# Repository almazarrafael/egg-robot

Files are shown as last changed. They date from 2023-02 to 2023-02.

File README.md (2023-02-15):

# egg-robot
Self-balancing PID controlled robot on the Arduino.

egg is a robot that is capable of self-balancing. This is done through a PID controller that takes in IMU data that determines its pitch angles and outputs motor values. The idea is to correct the error between the actual pitch angle to a setpoint. The setpoint angle is the angle where the robot is standing vertically. The PID controller then takes this error and outputs values that the motors can use. Three different components are at play when it comes with PID controllers. Proportional, integral and derivative components which include their own gains (Kp, Ki, Kd). These gains need to be tuned accordingly in order to achieve self-balancing.

| egg Front View | dumpling Side View |
|:---:|:---:|
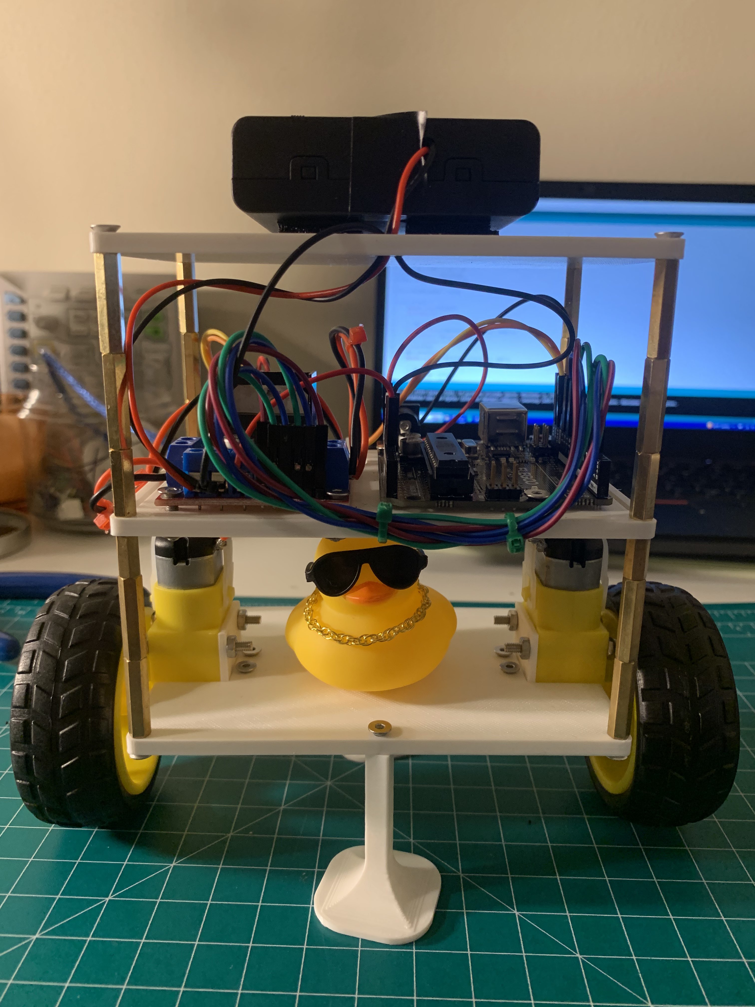
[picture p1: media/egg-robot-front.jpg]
dumpling
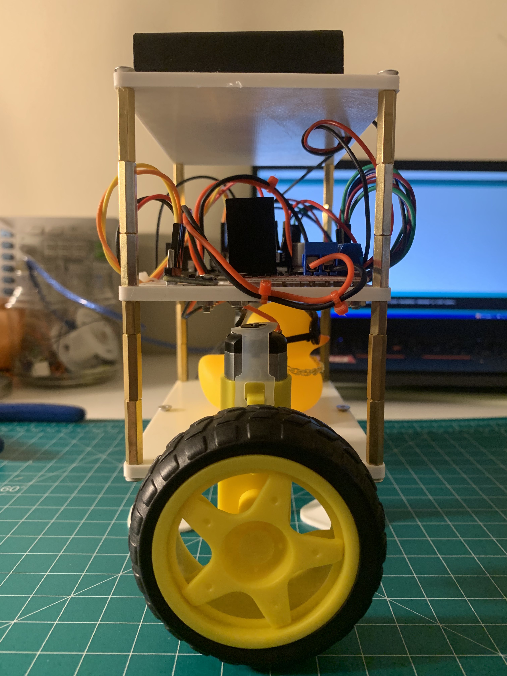
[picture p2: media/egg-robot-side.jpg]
dumpling_top
|||

### Parts List

- Arduino
- 2x TT motors
- L298N motor driver
- MPU6050 IMU
- 6V Battery pack
- 3D printed chassis
  - Base plate
  - Top plate for components
  - Top plate for battery
  - Motor mounts for base plate
  - Display stands
- Standoffs
- Various harnessing

### Tuning strategy

- Set Ki and Kd to 0.
- Increase Kp gain
  - Too low then the robot can't recover
  - Too high then the robot starts oscillating
  - A good Kp will allow the robot to stand almost on its own
- Once Kp is chosen, increase Kd. An increase in Kd will mitigate oscillations but if set too high then it will cause jitters.
- A PD controller will have steady-state error and this can be seen when the robot tilts one way consistently.
- Increase Ki until steady state error is gone.

### Resources

- [PID](http://brettbeauregard.com/blog/2011/04/improving-the-beginners-pid-introduction/)
- [PID tuning guide](https://www.youtube.com/watch?v=uyHdyF0_BFo)
- [MPU6050](https://lastminuteengineers.com/mpu6050-accel-gyro-arduino-tutorial/)
- [L298N](https://lastminuteengineers.com/l298n-dc-stepper-driver-arduino-tutorial/)

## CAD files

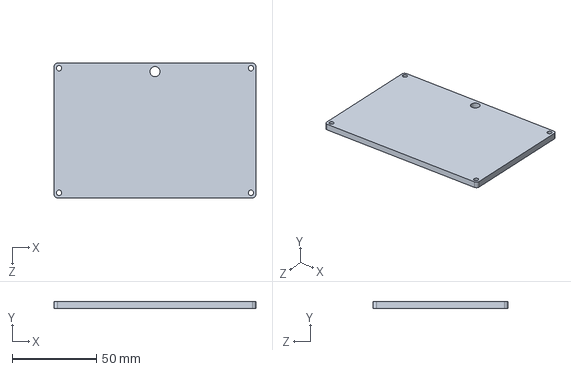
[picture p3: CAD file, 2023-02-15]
egg-models/SOLIDWORKS/top-plate-battery.SLDPRT
120.0 x 4.00 x 80.0 mm

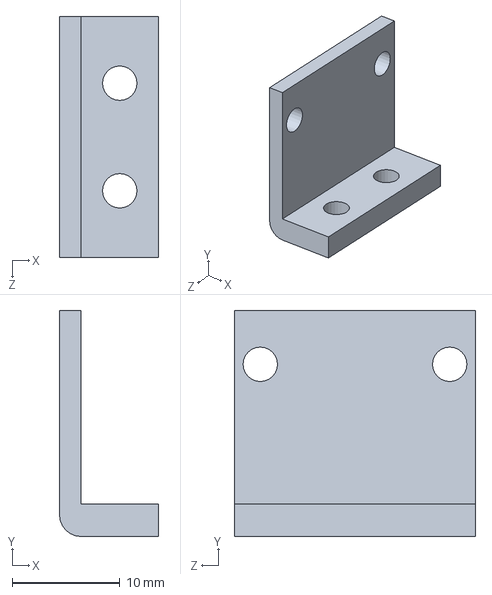
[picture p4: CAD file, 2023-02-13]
egg-models/SOLIDWORKS/motor-mount.SLDPRT
9.20 x 21.0 x 22.4 mm

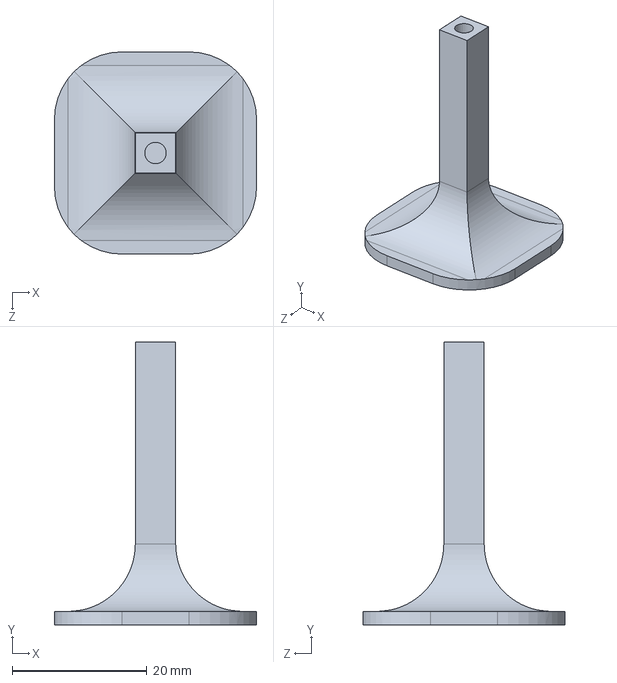
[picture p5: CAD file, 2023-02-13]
egg-models/SOLIDWORKS/display-stand.SLDPRT
30.0 x 42.0 x 30.0 mm

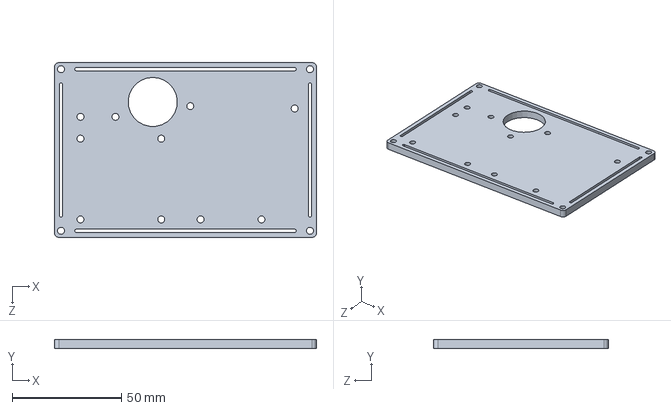
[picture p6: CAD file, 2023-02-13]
egg-models/SOLIDWORKS/top-plate.SLDPRT
120.0 x 4.00 x 80.0 mm

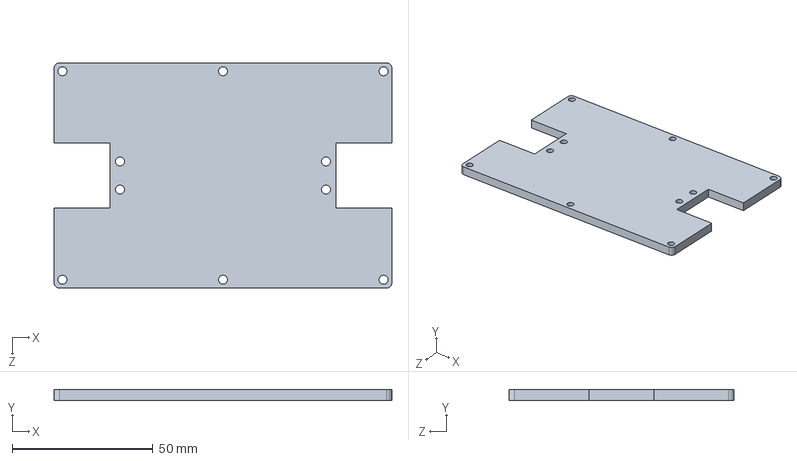
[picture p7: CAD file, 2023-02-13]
egg-models/SOLIDWORKS/base-plate.SLDPRT
120.0 x 4.00 x 80.0 mm

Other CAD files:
egg-models/STL/base-plate.STL
egg-models/STL/display-stand.STL
egg-models/STL/motor-mount.STL
egg-models/STL/top-plate-battery.STL
egg-models/STL/top-plate.STL

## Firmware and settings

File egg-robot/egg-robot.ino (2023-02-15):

#include "Wire.h"
#include <MPU6050_light.h>

// MPU
MPU6050 mpu(Wire);

// Pin definitions
#define enA 11 // PWM 
#define in1 12 // Forward
#define in2 13 // Backward

#define enB 3 // PWM
#define in3 4 // Backward
#define in4 5 // Forward

// PID values
float yRotation; // PID input
int output;
float setpoint = 0;
int sampleTime = 10;
int outMin = -255;
int outMax = 255;

// PID calculation
unsigned long lastTime;
float errSum;
float lastErr;

// PID tuning
double kp = 100; // Ku = 35
double ki = 0.5 * sampleTime;
double kd = 0.05 / sampleTime;

bool fallDetected = false;

void setup() {
    Serial.begin(115200);
    Wire.begin();

    // MPU
    Serial.println("MPU6050 calibration: START");
    byte status = mpu.begin();
    while (status != 0) { }
    delay(1000);
    mpu.calcOffsets();
    Serial.println("MPU6050 calibration: END");
    
    // Motor A
    pinMode(enA, OUTPUT);
    pinMode(in1, OUTPUT);
    pinMode(in2, OUTPUT);

    // Motor B
    pinMode(enB, OUTPUT);
    pinMode(in3, OUTPUT);
    pinMode(in4, OUTPUT);
}

void loop() {
  while (true) {
    mpu.update();
    yRotation = mpu.getAngleY();

    // Stops moving when the angle gets too steep and unrecovarable
    if (abs(yRotation) > 30) {
      motor_control(0);
      break;
    }
    
    Serial.print("Y: "); Serial.println(yRotation);
    
    output = PID_compute(yRotation);
    Serial.println(output);
    
    motor_control(output);
  }
}

int PID_compute (float input) {
  int output;
  double iTerm;
  
  unsigned long now = millis();
  int timeChange = (double)(now - lastTime);

  if (timeChange >= sampleTime) {
    double error = setpoint - input;
    errSum += error;
    double dErr = (error - lastErr);

    iTerm = ki*errSum;
    // reset windup mitigation: integral
    if (iTerm > outMax) iTerm = outMax;
    else if (iTerm < outMin) iTerm = outMin;

    output = (kp*error) + (iTerm) + (kd*dErr);
    // reset windup mitigation: output
    if (output > outMax) output = outMax;
    else if (output < outMin) output = outMin;

    lastErr = error;
    lastTime = now;
  }
  
  return output;
}

void motor_control(int val) {
    // Val should range from -255 to 255, but just in case
    val = constrain(val, -255, 255);

    // Values less than 30 doesn't make the motor move
    if (abs(val) < 30) {
      val = 0;
    }
    
    if (val > 0) {
        digitalWrite(in1, HIGH);
        digitalWrite(in4, HIGH);

        digitalWrite(in2, LOW);
        digitalWrite(in3, LOW);

        analogWrite(enA, val);
        analogWrite(enB, val);
    }
    else if (val < 0) {
        digitalWrite(in1, LOW);
        digitalWrite(in4, LOW);

        digitalWrite(in2, HIGH);
        digitalWrite(in3, HIGH);

        analogWrite(enA, -1*val);
        analogWrite(enB, -1*val);
    }
    else {
        digitalWrite(in1, LOW);
        digitalWrite(in4, LOW);

        digitalWrite(in2, LOW);
        digitalWrite(in3, LOW);

        analogWrite(enA, 0);
        analogWrite(enB, 0);
    }
}

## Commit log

2023-02-13 almazarrafael: 3d models done
    [base-plate.SLDPRT, base-plate.STL, display-stand.SLDPRT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]
2023-02-15 almazarrafael: PID done, needs tuning
2023-02-15 almazarrafael: self-balance works, needs fine tuning to remove jitters
    [egg-robot.ino]
2023-02-15 almazarrafael: added battery plate for better balance
    [top-plate-battery.SLDPRT]
